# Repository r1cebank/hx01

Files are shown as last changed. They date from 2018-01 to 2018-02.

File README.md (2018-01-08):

# MX01

A 8-bit CPU design

Recently I've been reading a lot about electroincs. I found building a 8-bit CPU from scratch will help me understand how modern CPU is designed.

__Note:__  I am a software developer by trade, but I always interested in electroincs. During college years, I have made multiple projects using Arduino, Netduino. I also coded a multi threaded os for Netduino. Building this 8 bit CPU is diffcult and I am basically follwing what's in the Digital Computer Electroincs by Malvino. If any of you reading this is electric engineer by trade and find anything to improve. Please let me know. Thank You

## Resources

[Building 8-bit computer](https://eater.net/8bit/) 

[Digital Computer Electronics](https://books.google.ca/books/about/Digital_Computer_Electronics.html?id=1QaMPwAACAAJ&redir_esc=y&hl=en)

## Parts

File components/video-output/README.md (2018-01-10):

# Video Output

The original design from Ben Eater does not have a solution to output video. But because we are building a "computer" we need a way to display output other than the 7 segment display. 

## High level design

We are following the retro design of video output. The entire system work as follows:

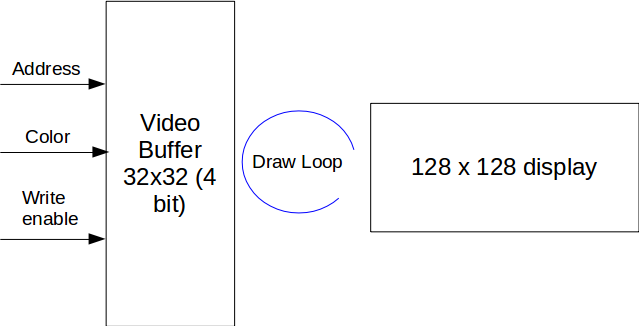
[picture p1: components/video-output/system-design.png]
system design


The video output system works separately from the entire system, it hooks up with the existing system (basically the display buffer is an extension of existing computer memory). The address range is undetermined. 

## How it works?

The framebuffer and display works on the separately Arduino board. Initially when the system is booted up, it will clear the framebuffer and create a loop that runs at 60hz dumping values from framebuffer to the display. It also sets an interrupt on the write line, so when the line goes from high to low (or low to high) it will modify the pixel value from that address.

## Parts

* Adafruit 1.44" TFT LCD [link](http://adafru.it/2088)
* Arduino Micro [link](https://store.arduino.cc/usa/arduino-micro)

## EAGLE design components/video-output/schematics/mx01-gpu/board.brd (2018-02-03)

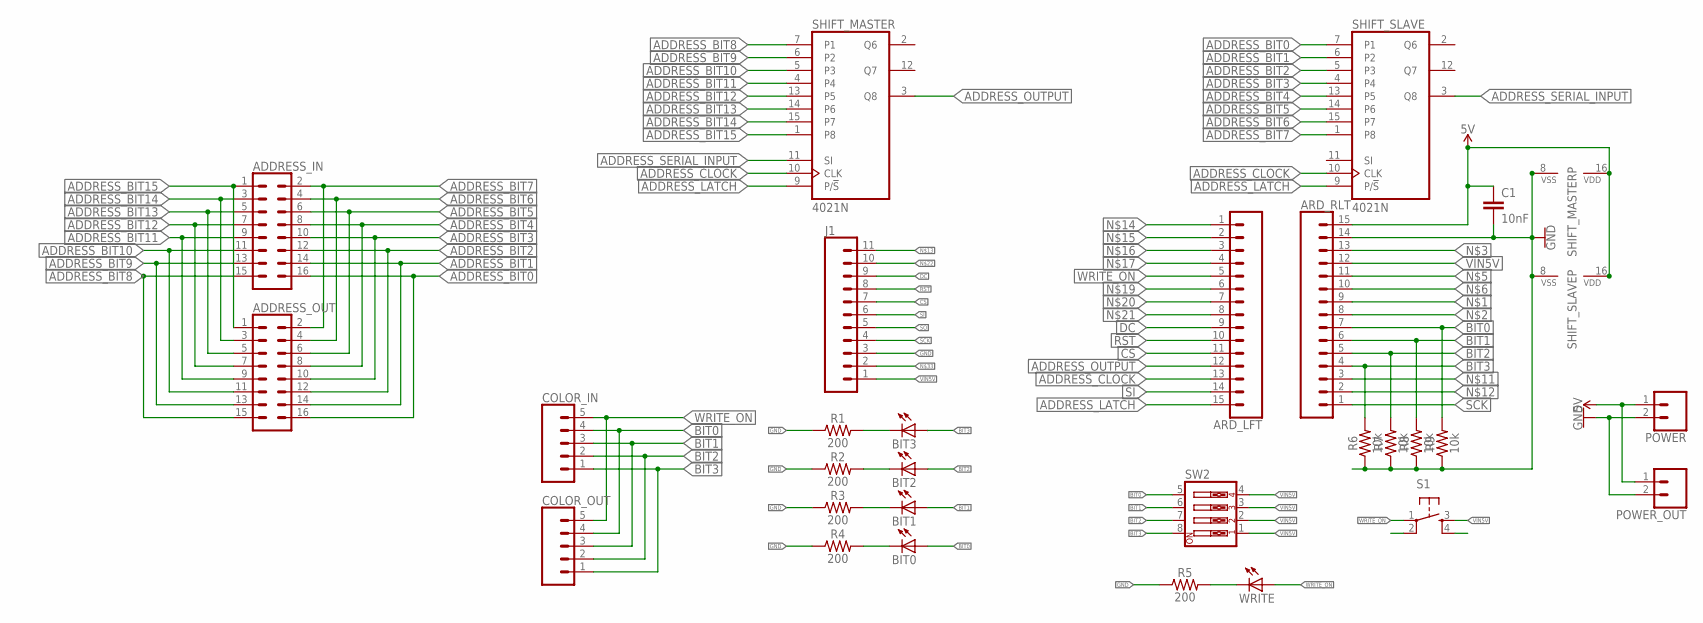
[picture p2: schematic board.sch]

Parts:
ADDRESS_IN: CONN_08X2; 2X8
ADDRESS_OUT: CONN_08X2; 2X8
ARD_LFT: CONN_15; 1X15
ARD_RLT: CONN_15; 1X15
BIT0, BIT1, BIT2, BIT3: LED5MM
C1: 10nF; CAP-PTH-10MM
COLOR_IN: CONN_05; 1X05
COLOR_OUT: CONN_05; 1X05
J1: CONN_11; 1X11
POWER: CONN_02; 1X02
POWER_OUT: CONN_02; 1X02
R1, R2, R3, R4, R5: 200; AXIAL-0.3
R6, R7, R8, R9: 10k; AXIAL-0.3
S1: TAC_SWITCHPTH; TACTILE-PTH
SHIFT_MASTER: 4021N; DIL16
SHIFT_SLAVE: 4021N; DIL16
SW2: SW_DIP-4; EDG-04
WRITE: LED5MM

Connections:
5V: ARD_RLT.15, C1.1, POWER.1, POWER_OUT.1, SHIFT_MASTER.16 (VDD), SHIFT_SLAVE.16 (VDD)
ADDRESS_BIT0: ADDRESS_IN.16, ADDRESS_OUT.16, SHIFT_SLAVE.7 (P1)
ADDRESS_BIT1: ADDRESS_IN.14, ADDRESS_OUT.14, SHIFT_SLAVE.6 (P2)
ADDRESS_BIT2: ADDRESS_IN.12, ADDRESS_OUT.12, SHIFT_SLAVE.5 (P3)
ADDRESS_BIT3: ADDRESS_IN.10, ADDRESS_OUT.10, SHIFT_SLAVE.4
ADDRESS_BIT4: ADDRESS_IN.8, ADDRESS_OUT.8, SHIFT_SLAVE.13 (P5)
ADDRESS_BIT5: ADDRESS_IN.6, ADDRESS_OUT.6, SHIFT_SLAVE.14 (P6)
ADDRESS_BIT6: ADDRESS_IN.4, ADDRESS_OUT.4, SHIFT_SLAVE.15 (P7)
ADDRESS_BIT7: ADDRESS_IN.2, ADDRESS_OUT.2, SHIFT_SLAVE.1 (P8)
ADDRESS_BIT8: ADDRESS_IN.15, ADDRESS_OUT.15, SHIFT_MASTER.7 (P1)
ADDRESS_BIT9: ADDRESS_IN.13, ADDRESS_OUT.13, SHIFT_MASTER.6 (P2)
ADDRESS_BIT10: ADDRESS_IN.11, ADDRESS_OUT.11, SHIFT_MASTER.5 (P3)
ADDRESS_BIT11: ADDRESS_IN.9, ADDRESS_OUT.9, SHIFT_MASTER.4
ADDRESS_BIT12: ADDRESS_IN.7, ADDRESS_OUT.7, SHIFT_MASTER.13 (P5)
ADDRESS_BIT13: ADDRESS_IN.5, ADDRESS_OUT.5, SHIFT_MASTER.14 (P6)
ADDRESS_BIT14: ADDRESS_IN.3, ADDRESS_OUT.3, SHIFT_MASTER.15 (P7)
ADDRESS_BIT15: ADDRESS_IN.1, ADDRESS_OUT.1, SHIFT_MASTER.1 (P8)
ADDRESS_CLOCK: ARD_LFT.13, SHIFT_MASTER.10 (CLK), SHIFT_SLAVE.10 (CLK)
ADDRESS_LATCH: ARD_LFT.15, SHIFT_MASTER.9 (P/!S), SHIFT_SLAVE.9 (P/!S)
ADDRESS_OUTPUT: ARD_LFT.12, SHIFT_MASTER.3 (Q8)
ADDRESS_SERIAL_INPUT: SHIFT_MASTER.11 (SI), SHIFT_SLAVE.3 (Q8)
BIT0: ARD_RLT.7, BIT0.A, COLOR_IN.4, COLOR_OUT.4, R9.P$2 (2), SW2.5
BIT1: ARD_RLT.6, BIT1.A, COLOR_IN.3, COLOR_OUT.3, R8.P$2 (2), SW2.6
BIT2: ARD_RLT.5, BIT2.A, COLOR_IN.2, COLOR_OUT.2, R7.P$2 (2), SW2.7
BIT3: ARD_RLT.4, BIT3.A, COLOR_IN.1, COLOR_OUT.1, R6.P$2 (2), SW2.8
CS: ARD_LFT.11, J1.7
DC: ARD_LFT.9, J1.9
GND: ARD_RLT.14, C1.2, J1.3, POWER.2, POWER_OUT.2, R1.P$1 (1), R2.P$1 (1), R3.P$1 (1), R4.P$1 (1), R5.P$1 (1), R6.P$1 (1), R7.P$1 (1), R8.P$1 (1), R9.P$1 (1), SHIFT_MASTER.8 (VSS), SHIFT_SLAVE.8 (VSS)
unnamed: R5.P$2 (2), WRITE.K (C)
unnamed: BIT0.K (C), R4.P$2 (2)
unnamed: BIT1.K (C), R3.P$2 (2)
unnamed: BIT2.K (C), R2.P$2 (2)
unnamed: BIT3.K (C), R1.P$2 (2)
RST: ARD_LFT.10, J1.8
SCK: ARD_RLT.1, J1.4
SI: ARD_LFT.14, J1.6
SO: J1.5
VIN5V: ARD_RLT.12, J1.1, S1.3, SW2.1, SW2.2, SW2.3, SW2.4
WRITE_ON: ARD_LFT.5, COLOR_IN.5, COLOR_OUT.5, S1.1, WRITE.A

Board: 2 copper layers, 28 parts (0 on the bottom side), 38 nets, no tracks yet.

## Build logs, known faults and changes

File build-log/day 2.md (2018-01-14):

# Day 2 (Jan 13, 2018)

## Build

Video output component

## Build progress

I have written a very simple sketch in arduino using the same draw wait and update loop. I hooked up interrupts and also finalized a color list from 0-15

```c++
const uint16_t colorMap[] = {
    0x0000,
    0x8000,
    0xF800,
    0xF81F,
    0x0410,
    0x0400,
    0x07E0,
    0x07FF,
    0x0010,
    0x8010,
    0x001F,
    0xC618,
    0x8410,
    0x8400,
    0xFFE0,
    0xFFFF
};
```
I wired some led to the board to show the current value feeded to the arduino and also a switch to toggle write signal.

### Reference

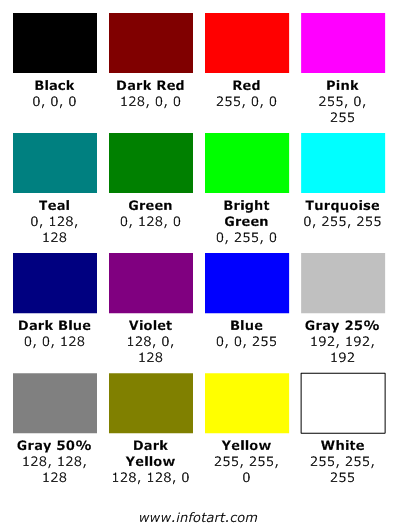
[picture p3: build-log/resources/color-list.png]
color list


## More information

### Pins

Digital 2 - update interrupt pin (FALLING trigger)

## Images

### Day 1

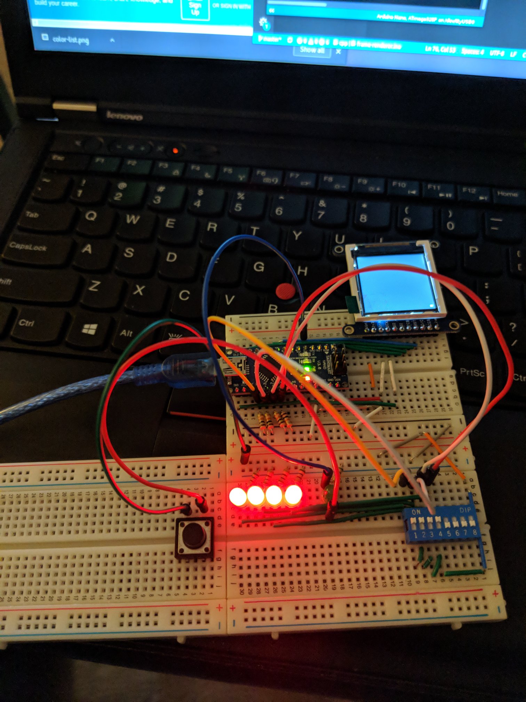
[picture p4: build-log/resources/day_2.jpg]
day 1


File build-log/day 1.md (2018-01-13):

# Day 0 (Jan 12, 2018)

## Build

Video output component

## Parts

* Adafruit 1.44 TFT LCD 128*128
* Arduino Micro (Nano)

* A bunch jumper wires
* Few LED
* Few 200ohm Resistor
* 8 bit dip switch
* 20k ohm resistor

## Build progress

When I tried to connect LCD to Arduino Micro, I have encountered a sketch upload issue that bricked the arduino. Currently that board is unable to be recognized by the computer, and my attempt to burn bootloader has failed. The Arduino Micro have this weird bootloader and no USB chip made them very easy to brick

I ordered some Arduino Nano clones from amazon, these do have dedicated USB chip and very easy to program. I was able to hook the LCD to Arduino and run the display test program. I am also waiting for the 8 bit shift register so I can build a 16 bit address input for the display. My original design is to make the display 4bit color. It is going to be indexed.

## More information

### Pins

A0-A3 (Analog as digital input) - color

## Images

### Day 1

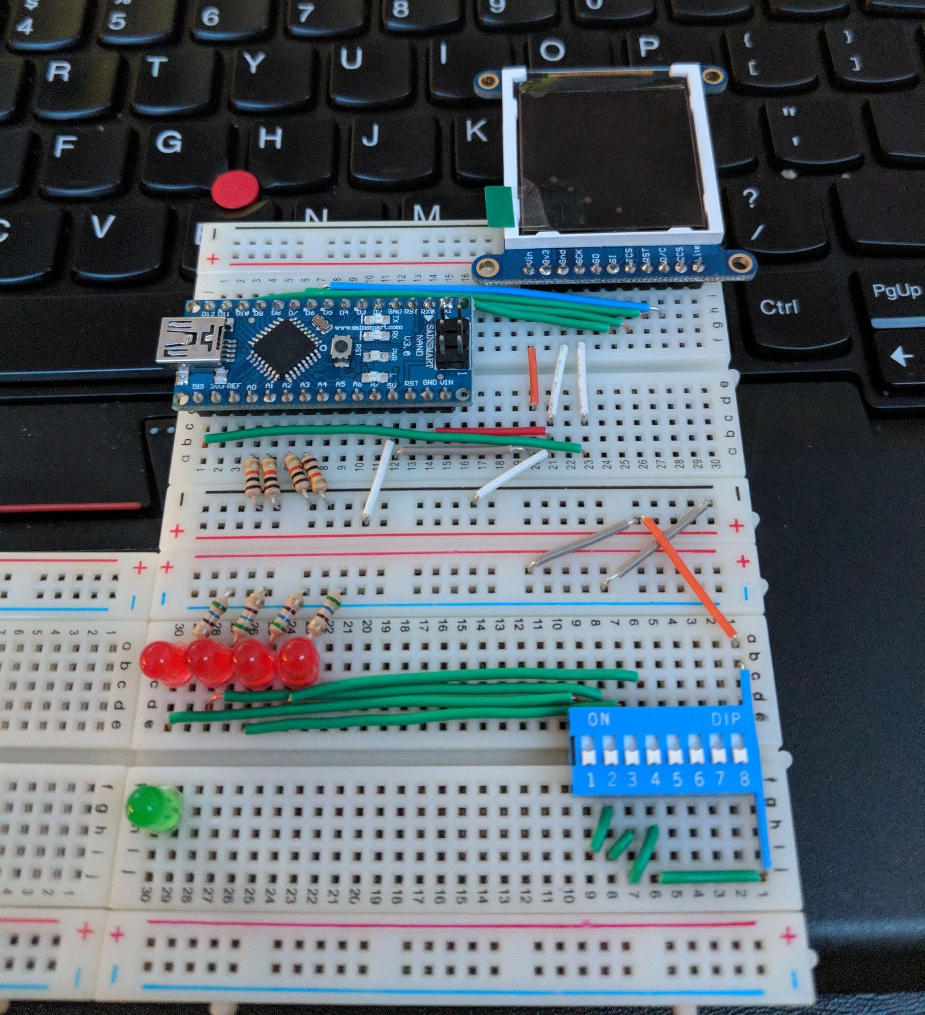
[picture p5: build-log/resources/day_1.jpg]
day 1


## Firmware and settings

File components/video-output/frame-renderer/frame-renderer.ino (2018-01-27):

#include <Adafruit_GFX.h>    // Core graphics library
#include <Adafruit_ST7735.h> // Hardware-specific library
#include <SPI.h>

// Pin configs
#define TFT_CS     8
#define TFT_RST    7
#define TFT_DC     6
#define INPUT_DATA 9
#define INPUT_CLOCK 10
#define INPUT_LATCH 12

const byte interruptPin = 2;
const byte color1bit = A3;
const byte color2bit = A2;
const byte color3bit = A1;
const byte color4bit = A0;

Adafruit_ST7735 tft = Adafruit_ST7735(TFT_CS,  TFT_DC, TFT_RST);

volatile byte frameBuffer[32][32];
volatile byte addressValue = 0;

const uint16_t colorMap[] = {
    0x0000,
    0x8000,
    0xF800,
    0xF81F,
    0x0410,
    0x0400,
    0x07E0,
    0x07FF,
    0x0010,
    0x8010,
    0x001F,
    0xC618,
    0x8410,
    0x8400,
    0xFFE0,
    0xFFFF
};

void setup() {
    // Init input
    pinMode(INPUT_DATA, INPUT);
    pinMode(INPUT_LATCH, OUTPUT);
    pinMode(INPUT_CLOCK, OUTPUT); 
    // Init serial
    Serial.begin(9600);
    Serial.println("Hello! mx01 gpu");
    // Init display
    tft.initR(INITR_144GREENTAB);
    tft.fillScreen(ST7735_YELLOW);
    // Fille framebuffer with black
    for (int i = 0; i < 32; i++) {
        for (int j = 0; j < 32; j++) {
            frameBuffer[i][j] = B00000000;
        }
    }
    // Attach write interrupt
    attachInterrupt(digitalPinToInterrupt(interruptPin), updateFramebuffer, FALLING);
}

void loop() {
    // put your main code here, to run repeatedly:
    renderBuffer();
}

byte boolArrayToByte(boolean* bits){
    int ret = 0;
    int tmp;
    for (int i = 0; i < 4; i++) {
        tmp = bits[i];
        ret |= tmp << (4 - i - 1);
    }
    return ret;
}

uint8_t fixedShiftIn(uint8_t dataPin, uint8_t clockPin, uint8_t bitOrder) {
	uint8_t value = 0;
	uint8_t i;

	for (i = 0; i < 8; ++i) {
		digitalWrite(clockPin, LOW);
		if (bitOrder == LSBFIRST)
			value |= digitalRead(dataPin) << i;
		else
			value |= digitalRead(dataPin) << (7 - i);
		digitalWrite(clockPin, HIGH);
	}
	return value;
}

void updateFramebuffer() {
    // read from register
    digitalWrite(INPUT_LATCH, 1);
    delayMicroseconds(20);

    //Set latch pin to 0 to get data from the CD4021
    digitalWrite(INPUT_LATCH, 0);

    //Get CD4021 register data in byte variable
    addressValue = fixedShiftIn(INPUT_DATA, INPUT_CLOCK, MSBFIRST);
    Serial.print(addressValue);
    Serial.print("-");
    Serial.println(addressValue, BIN);
    const boolean bit1 = digitalRead(color1bit);
    const boolean bit2 = digitalRead(color2bit);
    const boolean bit3 = digitalRead(color3bit);
    const boolean bit4 = digitalRead(color4bit);
    const boolean bits[] = {bit4, bit3, bit2, bit1};
    frameBuffer[1][1] = boolArrayToByte(bits); // Fixed address while I wait for shift register to arrive
}

void renderBuffer() {
    for (int y = 0; y < 32; y++) {
        for (int x = 0; x < 32; x++) {
            tft.fillRect(x * 4, y * 4 , 4, 4, colorMap[frameBuffer[x][y]]);
            // tft.drawRect(tft.width()/2 -x/2, tft.height()/2 -x/2 , x, x, color2);
        }
    }
}

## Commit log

2018-01-20 adding schematics
    [board.sch]
2018-02-03 Finish board v.0.01
    [board.brd, board.sch]

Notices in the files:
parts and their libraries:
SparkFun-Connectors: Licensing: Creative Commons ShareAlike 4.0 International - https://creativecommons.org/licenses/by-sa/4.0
